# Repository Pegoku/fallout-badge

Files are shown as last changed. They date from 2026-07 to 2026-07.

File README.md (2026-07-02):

# Small Morse Code Handheld Devices

From: @Pegoku

ESP32-C3 based boards that connect to each other and let you send and receive messages using ESPNOW.

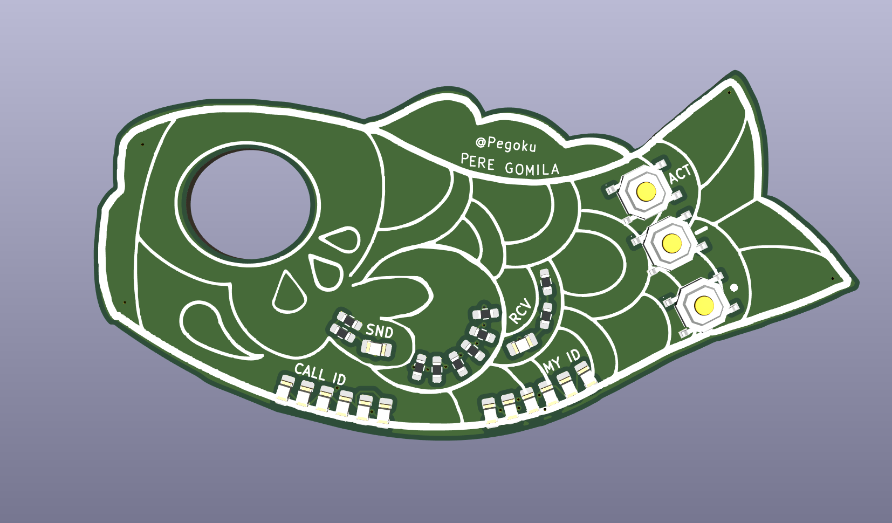
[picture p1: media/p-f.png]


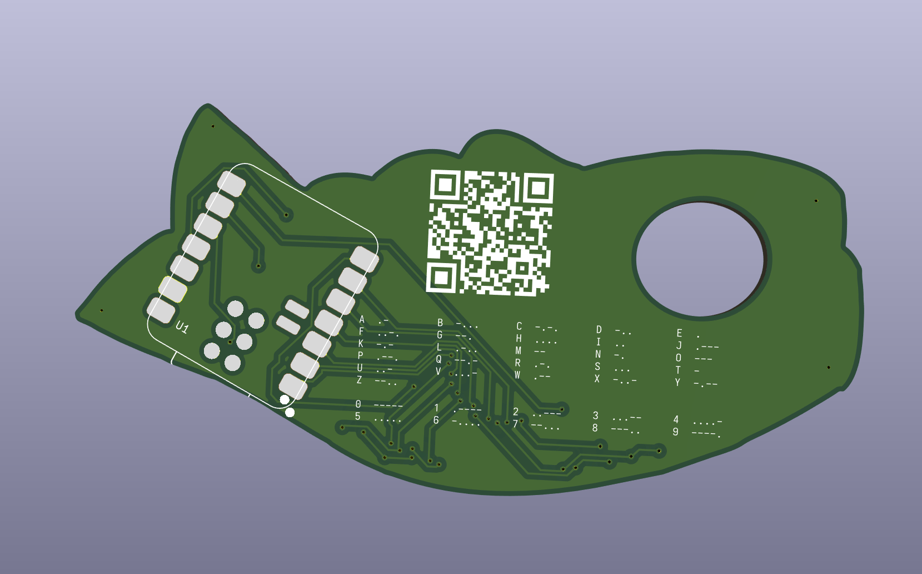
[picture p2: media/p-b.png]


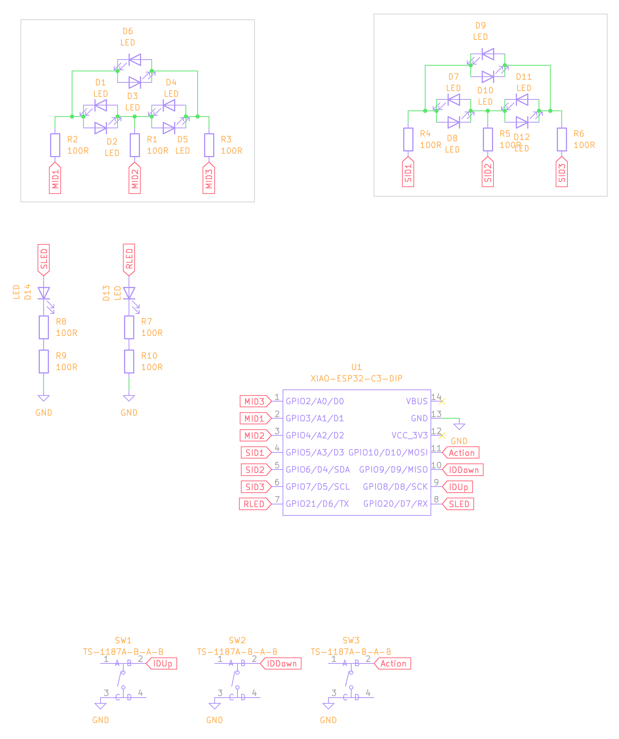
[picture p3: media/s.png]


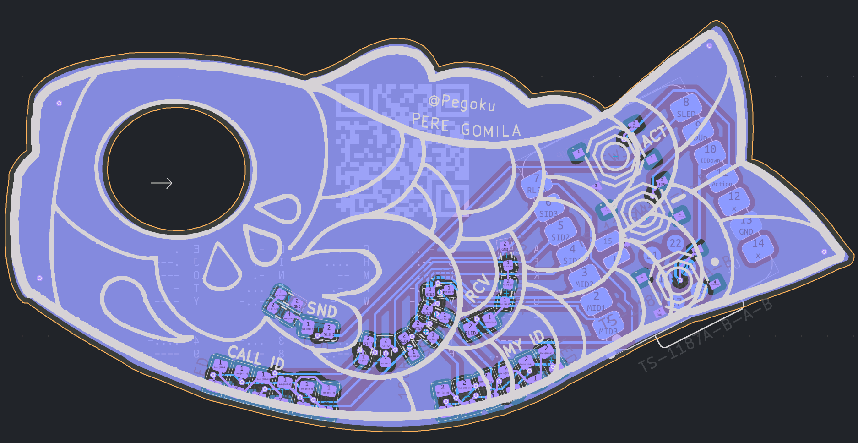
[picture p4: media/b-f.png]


## BOM (Per PCB)

| Item | Quantity | JLCPCB PN. |
| --- | --- | --- |
| XIAO ESP32-C3  | 1 | N/A |
| 100 Ω resistor | 10 | C22775 |
| Push button | 3 | C318884 |
| 0805 Red LED | 14 | C84256 |

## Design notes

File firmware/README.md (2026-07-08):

# Fallout Badge Firmware

Firmware for the ESP32-C3 Fallout badge.

Current firmware status: full ESP-NOW application firmware. It stores a local
badge ID, validates claimed IDs over ESP-NOW, selects a call target, handles
incoming/outgoing calls, and exchanges short/long/raw call inputs.

## Requirements

- ESP-IDF 6.x
- ESP32-C3 devboard connected over USB
- `cmake`, `ninja`, and the ESP-IDF toolchain

On this machine ESP-IDF is installed at:

```sh
/opt/esp-idf
```

Before using `idf.py`, source the ESP-IDF environment:

```sh
. /opt/esp-idf/export.sh
```

## Select Board Pinout

Two ESP32-C3 mini devboard pinouts are supported. They use the same physical
connector positions, but the GPIO numbers printed on the boards differ.

Default:

```text
ESP32-C3 mini:       5V GND 3.3V 10 9 8 7 6 5 4 3 2 1 0
```

For the default XIAO ESP32-C3 schematic, the ID LEDs and buttons use the
working `GPIO10..GPIO2` mapping, while the two discrete indicators are wired
separately as `RLED=GPIO21` and `SLED=GPIO20`.

Alternative:

```text
ESP32-C3 Super Mini: 5V GND 3.3V 4 3 2 1 20 10 9 8 7 6 5
```

The Super Mini option applies this XIAO-to-Super-Mini signal remap:

```text
XIAO GPIO:        2 3 4 5 6 7 21 20 10 9 8
Super Mini GPIO: 5 6 7 8 9 10 20 1  4  3 2
```

To change the selected board:

```sh
. /opt/esp-idf/export.sh
idf.py menuconfig
```

Then choose:

```text
Fallout Badge -> ESP32-C3 devboard pinout
```

The default board is also set in `sdkconfig.defaults`:

```text
CONFIG_BADGE_BOARD_PINOUT_C3_MINI=y
```

## Build

```sh
. /opt/esp-idf/export.sh
idf.py set-target esp32c3
idf.py build
```

The output firmware is:

```text
build/fallout_badge.bin
```

## Flash And Monitor

With one ESP32-C3 connected:

```sh
. /opt/esp-idf/export.sh
idf.py flash monitor
```

If multiple serial devices are connected, pass the port explicitly:

```sh
idf.py -p /dev/ttyACM0 flash monitor
```

Exit the monitor with `Ctrl+]`.

## Usage

After flashing:

- The firmware logs the selected pinout at boot.
- The firmware logs the concrete GPIO map used for LEDs and buttons.
- If no local ID is saved, the badge enters My ID input.
- If a local ID is saved, the badge enters Main mode and shows it on My ID LEDs.

Controls:

- My ID input: `IDUp`/`IDDown` changes the local ID, including `0`.
- My ID input: hold `IDUp` or `IDDown` for 0.8 seconds to auto-repeat with acceleration.
- My ID input: `Action` validates and saves the selected ID. Selecting `0` runs automatic assignment.
- Main: `IDUp` or `IDDown` enters Who To Call mode.
- Main or Who To Call: hold `IDUp + IDDown` for 3 seconds to re-enter My ID input.
- Who To Call: `IDUp`/`IDDown` changes the target ID.
- Who To Call: hold `IDUp` or `IDDown` for 0.8 seconds to auto-repeat with acceleration.
- Who To Call: `Action` sends a call request.
- Who To Call: long-press `Action` cancels back to Main.
- Incoming call: short-press `Action` accepts.
- Incoming call: long-press `Action` rejects.
- Outgoing wait or active call: hold `IDUp + IDDown` for 3 seconds to end/cancel.
- Active call: holding `Action` live-streams the raw input; SLED turns on while pressed and the receiver's RLED mirrors it until release.
- Active call: short-press `IDDown` sends a short visible symbol.
- Active call: short-press `IDUp` sends a long visible symbol.
- Active call: short/long symbols are queued and sent sequentially with a short gap between pulses.
- Directed packets are acknowledged and retried if the ACK is missed, including call requests, call responses, call end, and active-call inputs. Broadcast discovery packets remain best-effort.

Display behavior:

- My ID LEDs show the local badge ID.
- Send ID LEDs show the selected target, incoming caller, or active peer.
- The editable LED group blinks in My ID input and Who To Call modes.
- SLED pulses on local sends and stays on while holding `Action` in an active call.
- SLED/RLED hold for readable short and long symbol durations during active-call inputs.
- RLED mirrors received raw-duration inputs.
- Incoming calls blink SLED and RLED together.

## Hardware Notes

- Buttons are configured as active-low with internal pull-ups.
- Some GPIOs are boot strapping pins depending on the selected board. Test reset behavior while holding each button.
- The default XIAO ESP32-C3 schematic puts RLED/SLED on GPIO21/GPIO20. These are UART-labelled pins, so console logging is configured for USB Serial/JTAG instead of UART.
- Charlieplex LED 0 is the rightmost LED.
- The measured My ID scan appeared as `4 3 2 5 1 0`, so My ID defaults to order `{1, 0, 2, 5, 4, 3}` in `main/badge_display.c`.
- The measured Call ID scan appeared as `4 5 0 1 2 3`, so Call ID defaults to order `{4, 5, 2, 3, 0, 1}` in `main/badge_display.c`.

## Useful Commands

Clean and rebuild:

```sh
idf.py fullclean
idf.py build
```

Open config:

```sh
idf.py menuconfig
```

Show configured badge pinout symbols:

```sh
rg "BADGE_BOARD_PINOUT" sdkconfig
```

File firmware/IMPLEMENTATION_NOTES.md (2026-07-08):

# Firmware Implementation Notes

## Current Status

Started Phase 1 and Phase 2 from `ImprovedPlan.md`.

Implemented:

- Native ESP-IDF project scaffold.
- ESP32-C3 devboard pin map toggle for the two supported mini-board pinouts.
- Initial charlieplex display driver for My ID and Send ID LEDs.
- Configurable logical-to-physical LED order arrays.
- Fixed SLED/RLED control and pulse helpers.
- Initial debounced button polling for IDUp, IDDown, and Action.
- Basic bring-up `app_main` that scans LED patterns and logs button events.

## Build Status

Native ESP-IDF is installed system-wide:

- ESP-IDF package: `esp-idf 6.0.1-1`.
- ESP-IDF path: `/opt/esp-idf`.
- Build tool: `/opt/esp-idf/tools/idf.py`.

`idf.py` is not on `PATH` until the ESP-IDF environment is sourced. Use:

```sh
. /opt/esp-idf/export.sh
```

Verified build command:

```sh
. /opt/esp-idf/export.sh && idf.py set-target esp32c3 && idf.py build
```

Build result:

- `build/fallout_badge.bin` generated successfully.
- App binary size: about `0x23350` bytes.
- Smallest app partition free space: about 86%.

Known environment warnings:

- Git reports dubious ownership for `/opt/esp-idf` because the package files are owned by `nobody`. The build still completes.
- ESP-IDF reports a few upstream Kconfig default-value notifications. They do not block this project build.

## Build And Flash Commands

From this directory, in a new shell:

```sh
. /opt/esp-idf/export.sh
idf.py set-target esp32c3
idf.py build
idf.py flash monitor
```

## Board Pinout Selection

The badge maps logical signals by physical connector position. Both supported
boards use the same positions, but the GPIO labels differ.

Default board:

```text
ESP32-C3 mini:       5V GND 3.3V 10 9 8 7 6 5 4 3 2 1 0
```

For the default XIAO ESP32-C3 schematic, the ID LEDs and buttons use the
working `GPIO10..GPIO2` mapping, while the two discrete indicators are wired
separately as `RLED=GPIO21` and `SLED=GPIO20`.

Alternative board:

```text
ESP32-C3 Super Mini: 5V GND 3.3V 4 3 2 1 20 10 9 8 7 6 5
```

The Super Mini firmware option applies this XIAO-to-Super-Mini signal remap:

```text
XIAO GPIO:        2 3 4 5 6 7 21 20 10 9 8
Super Mini GPIO: 5 6 7 8 9 10 20 1  4  3 2
```

To change the board:

```sh
. /opt/esp-idf/export.sh
idf.py menuconfig
```

Then select:

```text
Fallout Badge -> ESP32-C3 devboard pinout
```

The default can also be changed in `sdkconfig.defaults`.

Logical signal order across the 11 GPIO positions:

```text
Action IDDown IDUp SID3 SID2 SID1 MID2 MID1 MID3 RLED SLED
```

## Hardware Bring-Up Notes

- Buttons are currently configured as active-low with internal pull-ups.
- Some selected GPIOs are boot strapping sensitive depending on the board. Test reset behavior while holding each button.
- The default XIAO ESP32-C3 schematic puts RLED/SLED on GPIO21/GPIO20. These are UART-labelled pins, so serial logging should stay on USB Serial/JTAG rather than UART.
- Charlieplex LED 0 is the rightmost LED.
- The measured My ID scan appeared as `4 3 2 5 1 0`, so My ID defaults to order `{1, 0, 2, 5, 4, 3}` to display visible LED order `0 1 2 3 4 5`.
- The measured Call ID scan appeared as `4 5 0 1 2 3`, so Call ID defaults to order `{4, 5, 2, 3, 0, 1}` to display visible LED order `0 1 2 3 4 5`.

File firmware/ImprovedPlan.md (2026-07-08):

# Fallout Badge Firmware Plan

## Feasibility Review

The feature set is feasible on the XIAO ESP32-C3 with ESP-NOW and FreeRTOS/ESP-IDF. The current hardware appears to fit the required signals exactly:

| Function | Net | XIAO / ESP32-C3 GPIO |
| --- | --- | --- |
| My ID charlieplex A | MID1 | GPIO3 / D1 |
| My ID charlieplex B | MID2 | GPIO4 / D2 |
| My ID charlieplex C | MID3 | GPIO2 / D0 |
| Send ID charlieplex A | SID1 | GPIO5 / D3 |
| Send ID charlieplex B | SID2 | GPIO6 / D4 |
| Send ID charlieplex C | SID3 | GPIO7 / D5 |
| Receive indicator LED | RLED | GPIO21 / D6 / TX |
| Send indicator LED | SLED | GPIO20 / D7 / RX |
| ID up button | IDUp | GPIO8 / D8 |
| ID down button | IDDown | GPIO9 / D9 |
| Action button | Action | GPIO10 / D10 |

Main risks and improvements:

1. GPIO8 and GPIO9 can affect ESP32-C3 boot strapping depending on board wiring and pull state. Validate that the buttons do not hold the chip in a bad boot mode when pressed during reset.
2. GPIO20/GPIO21 are UART RX/TX pins. Using them for LEDs is fine, but serial logging over those pins should be disabled or moved to USB CDC during normal firmware.
3. Automatic ID assignment cannot be guaranteed by simply pinging random IDs because two badges can choose the same ID at the same time. Use a probe/claim handshake with random backoff and store the accepted ID in NVS.
4. ESP-NOW is appropriate for short low-latency packets, but it is not guaranteed delivery. Add sequence numbers, acknowledgements for call control packets, and tolerate dropped realtime button-duration packets.
5. Charlieplexing and button scanning must be coordinated so display refresh does not cause ghosting or accidental button reads. Keep LED refresh in one task/driver and keep buttons on independent GPIO inputs with debounce.

## Firmware Stack

Use native ESP-IDF with FreeRTOS. Keep the code structured as ESP-IDF components:

- `app_main`: initializes NVS, GPIO, display, buttons, ESP-NOW, and app state.
- `drivers/display`: charlieplex refresh and fixed indicator LEDs.
- `drivers/buttons`: debounced button events with press, release, hold, and chord detection.
- `comms/espnow`: peer setup, packet encode/decode, send queue, receive callback.
- `app/state_machine`: all badge modes and transitions.
- `app/id_manager`: manual ID selection, automatic ID probing, NVS persistence.
- `app/call_session`: call setup, accept/reject/end, realtime message exchange, inactivity timeout.

## Core Data Model

IDs are 6-bit values:

- `0`: reserved for "auto assign / unset"; never used as a normal badge ID.
- `1..63`: valid badge IDs.
- Broadcast ESP-NOW peer is used for discovery, ID probing, and initial call requests.

Runtime state:

- `my_id`: current local badge ID.
- `target_id`: selected outgoing call target.
- `mode`: current UI state.
- `active_call_peer_id`: remote ID for the active call, if any.
- `last_activity_ms`: updated by accepted call traffic and local call input.
- `pending_call`: incoming caller ID and timeout data.
- `held_callers`: small list or bitset of callers that tried to call during an active call.

Persistent NVS values:

- Last confirmed `my_id`.
- Optional firmware/protocol version for future migrations.

## ESP-NOW Protocol

Use a compact fixed binary packet. Every packet includes:

- `magic`: identifies this project.
- `version`: protocol version.
- `type`: packet type.
- `src_id`: sender badge ID.
- `dst_id`: destination badge ID, or `0` for broadcast.
- `seq`: monotonically increasing packet sequence.
- `payload`: packet-specific data.

Packet types:

- `ID_PROBE`: asks whether an ID is already in use.
- `ID_PROBE_ACK`: sent by a badge that owns the probed ID.
- `ID_CLAIM`: announces that a badge is claiming an ID after a quiet probe window.
- `ID_CONFLICT`: optional warning sent when a badge sees another badge using its own ID.
- `CALL_REQUEST`: asks a target badge to start a call.
- `CALL_ACCEPT`: accepts a pending call.
- `CALL_REJECT`: rejects a pending call.
- `CALL_HOLD`: tells a caller that the target is busy but noticed the request.
- `CALL_END`: ends an active call.
- `CALL_INPUT_RAW`: sends an action-button duration in milliseconds.
- `CALL_INPUT_SHORT`: sends a short symbol.
- `CALL_INPUT_LONG`: sends a long symbol.
- `PING`: optional presence/keepalive.

Reliability rules:

- Control packets (`CALL_REQUEST`, `CALL_ACCEPT`, `CALL_REJECT`, `CALL_HOLD`, `CALL_END`, `ID_CLAIM`, `ID_CONFLICT`) are resent a small fixed number of times until acknowledged or timed out.
- Realtime input packets may be sent once to preserve responsiveness.
- Duplicate packets are ignored using `(src_id, seq)`.

## Build System Decision

Use native ESP-IDF as the primary developer workflow. This aligns the project with Espressif's official tooling and keeps Wi-Fi/ESP-NOW configuration, flashing, monitoring, and debugging closest to the upstream documentation.

PlatformIO pros:

- Easier dependency, serial monitor, upload, and board configuration workflow.
- Good fit for quick iteration from VS Code or the command line.
- Can still target ESP-IDF instead of Arduino.

PlatformIO cons:

- Adds one extra layer between the project and upstream ESP-IDF.
- Some ESP-IDF examples/docs assume native `idf.py`, so commands may need translation.
- Advanced ESP-IDF configuration can be slightly less transparent.

Native ESP-IDF pros:

- Official Espressif workflow with best documentation alignment.
- Simplest path for advanced Wi-Fi/ESP-NOW debugging and SDK configuration.
- Less abstraction when chasing low-level build or runtime issues.

Native ESP-IDF cons:

- More setup friction for contributors.
- Board/upload/monitor workflow is less compact than PlatformIO for small projects.
- Requires everyone to keep the ESP-IDF environment installed and sourced correctly.

Decision:

- Primary workflow: native ESP-IDF with `idf.py`.
- Optional future workflow: PlatformIO can be added later as a convenience wrapper if useful.
- The source tree should avoid PlatformIO-only assumptions.

## UI State Machine

### Boot

1. Initialize drivers and ESP-NOW.
2. Load `my_id` from NVS.
3. If no saved ID exists, enter `MY_ID_INPUT` with value `0`.
4. If a saved ID exists, display it on My ID LEDs and enter `MAIN`.

### My ID Input

Purpose: choose this badge's own ID.

Display:

- My ID LEDs blink while value is `0`.
- My ID LEDs show the selected 6-bit value for `1..63`.
- Send ID LEDs stay off.

Controls:

- `IDUp`: increment selected ID, wrapping `63 -> 0`.
- `IDDown`: decrement selected ID, wrapping `0 -> 63`.
- `Action` short press:
  - If selected ID is `1..63`, validate that the ID is not already in use before saving it and entering `MAIN`.
  - If selected ID is `0`, run automatic ID assignment.

Manual ID validation:

1. Broadcast `ID_PROBE(selected_id)`.
2. Wait a randomized probe window.
3. If any `ID_PROBE_ACK` is received, show an error blink/dance and stay in `MY_ID_INPUT`.
4. If no owner replies, broadcast `ID_CLAIM(selected_id)`, save it, and enter `MAIN`.

Automatic ID assignment:

1. Pick a random candidate from `1..63`.
2. Broadcast `ID_PROBE(candidate)`.
3. Wait a randomized probe window.
4. If no `ID_PROBE_ACK` is received, broadcast `ID_CLAIM(candidate)`.
5. Wait a second short randomized window.
6. If no conflict appears, save the ID and enter `MAIN`.
7. If a conflict appears, try a different candidate.

### Main

Purpose: idle, show this badge's ID, and listen for calls.

Display:

- My ID LEDs show `my_id`.
- Send ID LEDs off.
- SLED/RLED off except for brief receive/send activity pulses.

Controls:

- `IDUp` or `IDDown` short press: enter `WHO_TO_CALL`.
- Hold `IDUp + IDDown` for 3 seconds: enter `MY_ID_INPUT`.

Comms:

- Listen for `CALL_REQUEST` with `dst_id == my_id`.
- On valid incoming call, store caller ID and enter `CALL_RECEIVED`.
- If an `ID_PROBE` arrives for `my_id`, reply with `ID_PROBE_ACK`.
- If an `ID_CLAIM` or normal packet is seen from another badge using `my_id`, send `ID_CONFLICT` and show a conflict alert.

### Call Received

Purpose: accept or reject an incoming call.

Display:

- Blink SLED and RLED together.
- My ID LEDs continue showing `my_id`.
- Send ID LEDs show caller ID.

Controls:

- `Action` short press: send `CALL_ACCEPT`, enter `CALLING`.
- `Action` long press: send `CALL_REJECT`, enter `MAIN`.

Timeout:

- If the user does not respond within a configurable timeout, send `CALL_REJECT` and enter `MAIN`.

### Who To Call

Purpose: choose the remote badge ID.

Display:

- My ID LEDs show `my_id`.
- Send ID LEDs show selected `target_id`.

Controls:

- `IDUp`: increment target ID, wrapping `63 -> 1`.
- `IDDown`: decrement target ID, wrapping `1 -> 63`.
- `Action` short press: send `CALL_REQUEST`, enter `CALLING`.
- `Action` long press: clear target ID and return to `MAIN`.

Validation:

- Do not allow `target_id == 0`.
- If `target_id == my_id`, blink both ID groups as an error and stay in `WHO_TO_CALL`.

### Calling

Purpose: establish or run a bidirectional call.

Substates:

- `OUTGOING_WAIT_ACCEPT`: call request sent, waiting for accept/reject.
- `ACTIVE`: remote accepted; both badges can exchange messages.

Display:

- My ID LEDs show `my_id`.
- Send ID LEDs show remote ID.
- Pulse SLED on local send for short/long symbols and control traffic.
- Pulse RLED on remote receive for short/long symbols and control traffic.
- For raw action-button duration messages, the sender's SLED stays on for the full local press duration, and the receiver's RLED mirrors that duration. In the other direction, their SLED and my RLED should mirror the same way.

Controls in `OUTGOING_WAIT_ACCEPT`:

- Hold `IDUp + IDDown`: send `CALL_END`, enter `MAIN`.

Controls in `ACTIVE`:

- `Action` press/release: send `CALL_INPUT_RAW` with press duration in milliseconds.
- `IDDown` short press: send `CALL_INPUT_SHORT`.
- `IDUp` short press: send `CALL_INPUT_LONG`.
- Hold `IDUp + IDDown`: send `CALL_END`, enter `MAIN`.

Incoming calls during `ACTIVE`:

- Calls are strictly one-to-one.
- If a third badge sends `CALL_REQUEST`, reply with `CALL_HOLD` instead of accepting or rejecting.
- Add the caller to `held_callers` if there is room.
- Play a short "busy dance" on the Send ID LEDs, for example sweeping the six Send ID LEDs twice while preserving the active call state.
- When the active call ends, return to `MAIN`; held callers must call again rather than being auto-connected.

Timeouts:

- If the outgoing call is rejected or times out, enter `MAIN`.
- If there is 30 seconds of inactivity in `ACTIVE`, send `CALL_END` and enter `MAIN`.
- The inactivity timeout should be configurable with a compile-time constant.

## Display Driver Plan

Charlieplexing:

- Each 3-pin LED group controls 6 LEDs.
- Only one charlieplexed LED should be driven at a time per group.
- To light LED `n`, set one pin high, one pin low, and all other group pins high impedance.
- Refresh both 6-LED groups at a stable interval from a single display task or timer.

Display API:

- `display_set_my_id(uint8_t id, bool blink)`
- `display_set_target_id(uint8_t id, bool blink)`
- `display_pulse_send()`
- `display_pulse_receive()`
- `display_set_send_led(bool enabled)`
- `display_set_receive_led(bool enabled)`
- `display_set_call_alert(bool enabled)`
- `display_play_busy_dance()`
- `display_play_error_dance()`
- `display_tick()` if implemented without a dedicated task.

Implementation note:

- Start with a simple blocking scan during bring-up, then move refresh to a FreeRTOS task once button and comms code exists.
- LED bit order must be configurable with arrays, for example `my_id_led_order[6] = {0, 1, 2, 5, 4, 3}` and `send_id_led_order[6] = {0, 1, 2, 3, 4, 5}`. The state machine should think in logical bit positions; only the display driver maps those positions to physical LED indices.

## Button Driver Plan

Inputs:

- `IDUp`
- `IDDown`
- `Action`

Events:

- `BUTTON_PRESS`
- `BUTTON_RELEASE`
- `BUTTON_SHORT`
- `BUTTON_LONG`
- `BUTTON_HOLD_3S`
- `BUTTON_CHORD_UP_DOWN_3S`

Timing constants:

- Debounce: 20-40 ms.
- Long press: 600-1000 ms.
- Mode-change chord: 3000 ms.

The button driver should publish events to a FreeRTOS queue. The state machine consumes events and owns all interpretation.

## Implementation Milestones

### Phase 1: Project Scaffold

- Add ESP-IDF project files.
- Configure target for ESP32-C3/XIAO.
- Enable USB CDC logging if available.
- Add `sdkconfig.defaults` with Wi-Fi/ESP-NOW-friendly defaults.
- Confirm the firmware builds and boots.

Done when:

- A minimal firmware builds.
- Boot logs are visible.
- The app prints firmware version and reset reason.

### Phase 2: Hardware Bring-Up

- Define the GPIO pin map from the PCB.
- Implement fixed SLED/RLED control.
- Implement charlieplex LED test patterns.
- Implement configurable logical-to-physical LED order arrays for both charlieplex groups.
- Implement button input with debounce and event logging.

Done when:

- Every LED can be lit individually.
- Binary values can be displayed correctly after adjusting the LED order arrays.
- Every button reports short and long presses.
- Pressing buttons during reset does not break boot, or the risk is documented with a hardware workaround.

### Phase 3: Local UI State Machine

- Implement `MY_ID_INPUT`, `MAIN`, `WHO_TO_CALL`, and local transitions.
- Implement NVS save/load for `my_id`.
- Add display rendering for IDs and blinking/error states.

Done when:

- A single badge can select and persist its own ID.
- A target ID can be selected and cancelled.
- All local controls match the state machine.

### Phase 4: ESP-NOW Transport

- Initialize Wi-Fi station mode and ESP-NOW.
- Add broadcast peer.
- Implement packet struct, sequence numbers, duplicate filtering, and receive queue.
- Add debug command/log mode for sending test packets.

Done when:

- Two badges can exchange basic `PING` packets.
- SLED/RLED pulse on transmit/receive.
- Duplicate filtering is verified.

### Phase 5: ID Assignment

- Implement `ID_PROBE`, `ID_PROBE_ACK`, and `ID_CLAIM`.
- Use the same probe/claim flow for manual ID selection and automatic ID selection.
- Implement optional `ID_CONFLICT` handling for detected duplicate IDs.
- Add randomized backoff and conflict handling.
- Persist the assigned ID.

Done when:

- Multiple badges powered on together usually pick unique IDs.
- Manual ID conflicts are detected before saving when the conflicting badge is reachable.
- Duplicate-ID warnings are visible to the user when a conflict is detected later.

### Phase 6: Call Setup

- Implement `CALL_REQUEST`, `CALL_ACCEPT`, `CALL_REJECT`, `CALL_HOLD`, and `CALL_END`.
- Add outgoing wait, incoming call alert, accept/reject controls, and call cancellation.
- Add one-to-one busy handling and the busy dance for calls received during an active call.
- Add retries for control packets.

Done when:

- Badge A can call badge B.
- Badge B can accept or reject.
- Badge B replies with hold/busy behavior if Badge C calls while Badge B is already in a call.
- Both badges return to `MAIN` on reject, timeout, or call end.

### Phase 7: Realtime Call Input

- Implement raw action-button duration messages.
- Implement short and long symbol messages from `IDDown` and `IDUp`.
- Keep local SLED on for the full raw action-button press duration.
- Keep remote RLED on for the received raw action-button duration.
- Keep call traffic non-blocking with send/receive queues.
- Add 30-second inactivity timeout.

Done when:

- Inputs can be exchanged in both directions during an active call.
- The sender's SLED and receiver's RLED stay synchronized for raw duration messages in both directions.
- Sending does not block receiving.
- Inactivity and manual end both close the call cleanly.

### Phase 8: Polish and Hardening

- Tune button timings and LED refresh rate.
- Reduce logging for release builds.
- Add packet version checks.
- Add basic fault handling for ESP-NOW send failures.
- Add a simple diagnostics mode if flash space allows.

Done when:

- Two or more badges can run through the full flow repeatedly.
- Cold boot, reset, and reconnect behavior are predictable.
- Known limitations are documented in `README.md`.

## Test Plan

Single badge tests:

- Boot with no saved ID.
- Manual ID selection for `1`, `63`, and wraparound.
- Auto ID path with no other badges present.
- Button short, long, and chord detection.
- All LEDs and binary display values.
- NVS persistence across reset.

Two badge tests:

- Manual unique IDs and ping.
- Manual duplicate ID attempt while the other badge is reachable.
- Incoming call accept.
- Incoming call reject.
- Outgoing call timeout.
- Manual call end from either side.
- Raw duration send accuracy within acceptable tolerance.
- Sender SLED and receiver RLED synchronization during raw action-button messages.
- Short/long symbol exchange in both directions.

Multi badge tests:

- Auto ID assignment with three or more badges.
- Two badges attempting the same ID.
- One badge receiving a call while another call request is nearby.
- Busy/hold response and busy dance while already in an active call.
- Packet loss simulation by increasing distance or shielding one badge.

## Finalized Decisions

- Active calls are one-to-one. Extra callers receive `CALL_HOLD`, and the called badge plays a short Send ID LED busy dance.
- Manual ID selection uses the same probe/claim conflict avoidance as automatic ID assignment.
- The primary workflow is native ESP-IDF with `idf.py`.
- LED bit order is configurable with arrays in the display driver.
- Raw action-button messages are visualized as synchronized duration indicators: sender SLED on while pressed, receiver RLED on for the same duration.

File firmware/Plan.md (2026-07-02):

## Hardware capabilities:
XIAO ESP32-C3
6 My ID LEDs charlieplexed
6 Your ID LEDs charlieplexed
1 Send LED (to check what you're sending)
1 Recieve LED (to check what you're recieving)

For more information on how the components are connected, check ../pegoku-fallout-badge's schematic.

## Functionality

The device has many modes/states it can be in.

### My ID input mode

After powering on, it will be in this mode. It will ask for an ID, and the "My Id" LEDs will blink until the user press up or down, and then it will, in binary, display the ID. It goes from 000001 to 111111 (1 to 63)
then, you'll need to press the action button.

If the id is 000000, it will check for which id is available, by "pinging" each other device by using random IDs until the id is "unique".

Now, the My ID LEDs will be set to your id.

### Main Mode

This mode is the default idle mode.

To enter My Id input mode you have to press and hold for 3 seconds both up and down buttons.

If you just press up or down, like one tap, it will enter Who to call mode.

While in this mode it will frequently check for calls to this device, if it recieves one, will go to Call Recieved mode.

### Call recieved mode

In this mode, both RLED and SLED will blink and the user can accept (by pressing the action button) or reject the call by holding the button down for longer. 

If it rejects it, it will go back to main mode.
If it accepts it it will enter Calling Mode.

### Who to call mode

In this mode, the user has to set an ID of which they want to call to, that's the Send LEDs. It will be inputed in the same way as the My ID input mode.
When the ID is set and the user presses the Action button, it will start start the call, and enter the calling mode

If the user Holds down the action button, it will clear the id it was selected and go back to the main mode.

### Calling mode 

In this mode, it will send a message to the device with the ID specified, and wait for the other device to accept or reject it.

If it is rejected, it will go back to main mode.

When the user accepts the call, the call will begin, and bidirectionally the message interaction will be possible.

When the action button is pressed, it will send the "raw" duration of the press, so if the user presses for 312ms, 312ms will be sent.

But if the user presses the IDUp button, it will send a long message, and if they press the IDDown it will send a short message (morse code style).

The communication should be real time, not wait for the message to continue.

After 15 seconds of inactivity (configurable via #DECLARE) it will stop the call.

If the user wants to end the call early, they can press and hold both up and down buttons and it will end the call.

## Software

The project should use a RTOS (e.g. ESP-IDF)

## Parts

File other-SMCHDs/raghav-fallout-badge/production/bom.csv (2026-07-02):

Designator | Footprint | Quantity | Value | LCSC Part #
D1, D10, D11, D12, D13, D14, D2, D3, D4, D5, D6, D7, D8, D9 | 0805 | 14 | LED | C84256
R1, R10, R2, R3, R4, R5, R6, R7, R8, R9 | 0603 | 10 | 100R | C22775
SW1, SW2, SW3 | SW-SMD_4P-L5.1-W5.1-P3.70-LS6.5-TL_H1.5 | 3 | TS-1187A-B-A-B | C318884
U1 | XIAO-ESP32C3-SMD | 1 | XIAO-ESP32-C3-DIP

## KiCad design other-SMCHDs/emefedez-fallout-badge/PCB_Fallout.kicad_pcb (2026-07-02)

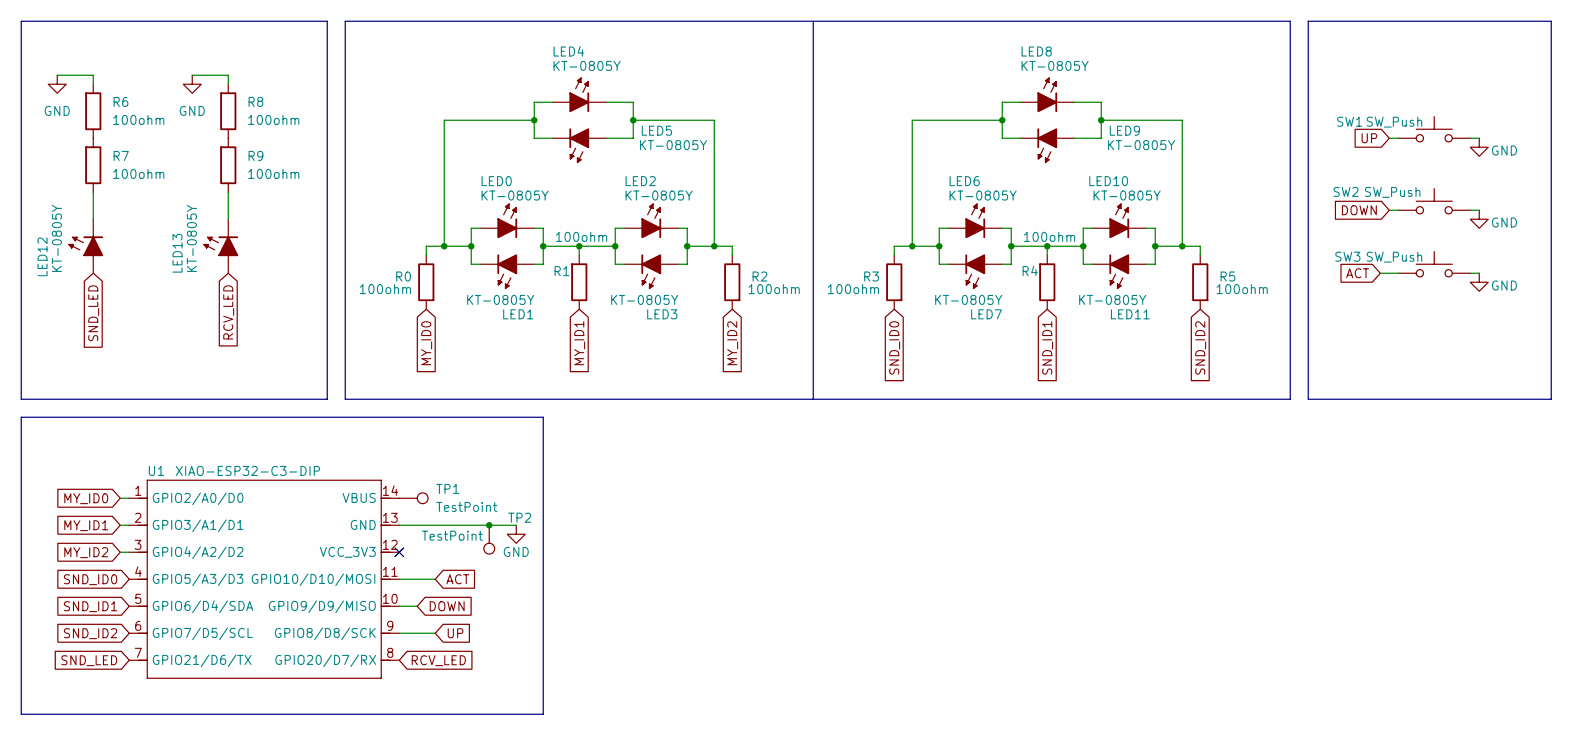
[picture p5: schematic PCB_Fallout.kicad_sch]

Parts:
LED0, LED1, LED2, LED3, LED4, LED5, LED6, LED7, LED8, LED9, LED10, LED11, LED12, LED13: KT-0805Y; LED_PLCC-2_3x2mm_KA
R0, R1, R2, R3, R4, R5, R6, R7, R8, R9: 100ohm; C_0805_2012Metric_Pad1.18x1.45mm_HandSolder
SW1, SW2, SW3: SW_Push; SW_SPST_TL3342
TP1, TP2: TestPoint; TestPoint_Pad_D1.0mm
U1: XIAO-ESP32-C3-DIP

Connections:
ACT: SW3.1, U1.11 (GPIO10/D10/MOSI)
DOWN: SW2.1, U1.10 (GPIO9/D9/MISO)
GND: R6.1, R8.1, SW1.2, SW2.2, SW3.2, TP2.1 (1_1), U1.13 (GND)
MY_ID0: R0.1, U1.1 (GPIO2/A0/D0)
MY_ID1: R1.2, U1.2 (GPIO3/A1/D1)
MY_ID2: R2.1, U1.3 (GPIO4/A2/D2)
unnamed: LED0.2 (A), LED1.1 (K), LED4.2 (A), LED5.1 (K), R0.2
unnamed: LED0.1 (K), LED1.2 (A), LED2.2 (A), LED3.1 (K), R1.1
unnamed: LED2.1 (K), LED3.2 (A), LED4.1 (K), LED5.2 (A), R2.2
unnamed: LED6.2 (A), LED7.1 (K), LED8.2 (A), LED9.1 (K), R3.2
unnamed: LED6.1 (K), LED7.2 (A), LED10.2 (A), LED11.1 (K), R4.1
unnamed: LED8.1 (K), LED9.2 (A), LED10.1 (K), LED11.2 (A), R5.2
unnamed: LED12.1 (K), R7.2
unnamed: LED13.1 (K), R9.2
unnamed: R6.2, R7.1
unnamed: R8.2, R9.1
unnamed: TP1.1 (1_1), U1.14 (VBUS)
RCV_LED: LED13.2 (A), U1.8 (GPIO20/D7/RX)
SND_ID0: R3.1, U1.4 (GPIO5/A3/D3)
SND_ID1: R4.2, U1.5 (GPIO6/D4/SDA)
SND_ID2: R5.1, U1.6 (GPIO7/D5/SCL)
SND_LED: LED12.2 (A), U1.7 (GPIO21/D6/TX)
UP: SW1.1, U1.9 (GPIO8/D8/SCK)

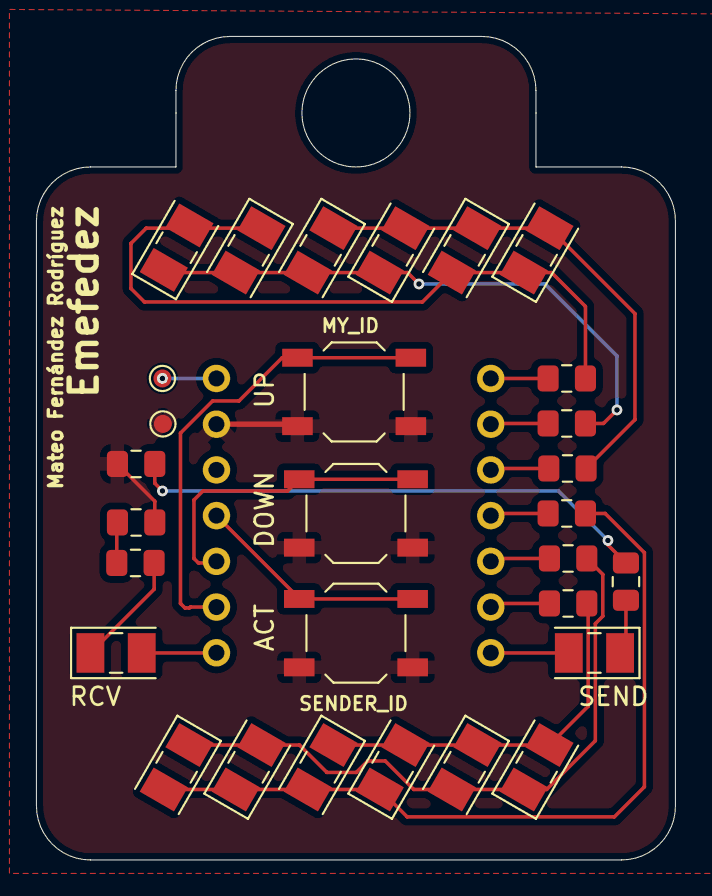
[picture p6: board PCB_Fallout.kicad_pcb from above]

Board: 2 copper layers, 35.5 x 45.8 mm, 30 parts (1 on the bottom side), 23 nets.

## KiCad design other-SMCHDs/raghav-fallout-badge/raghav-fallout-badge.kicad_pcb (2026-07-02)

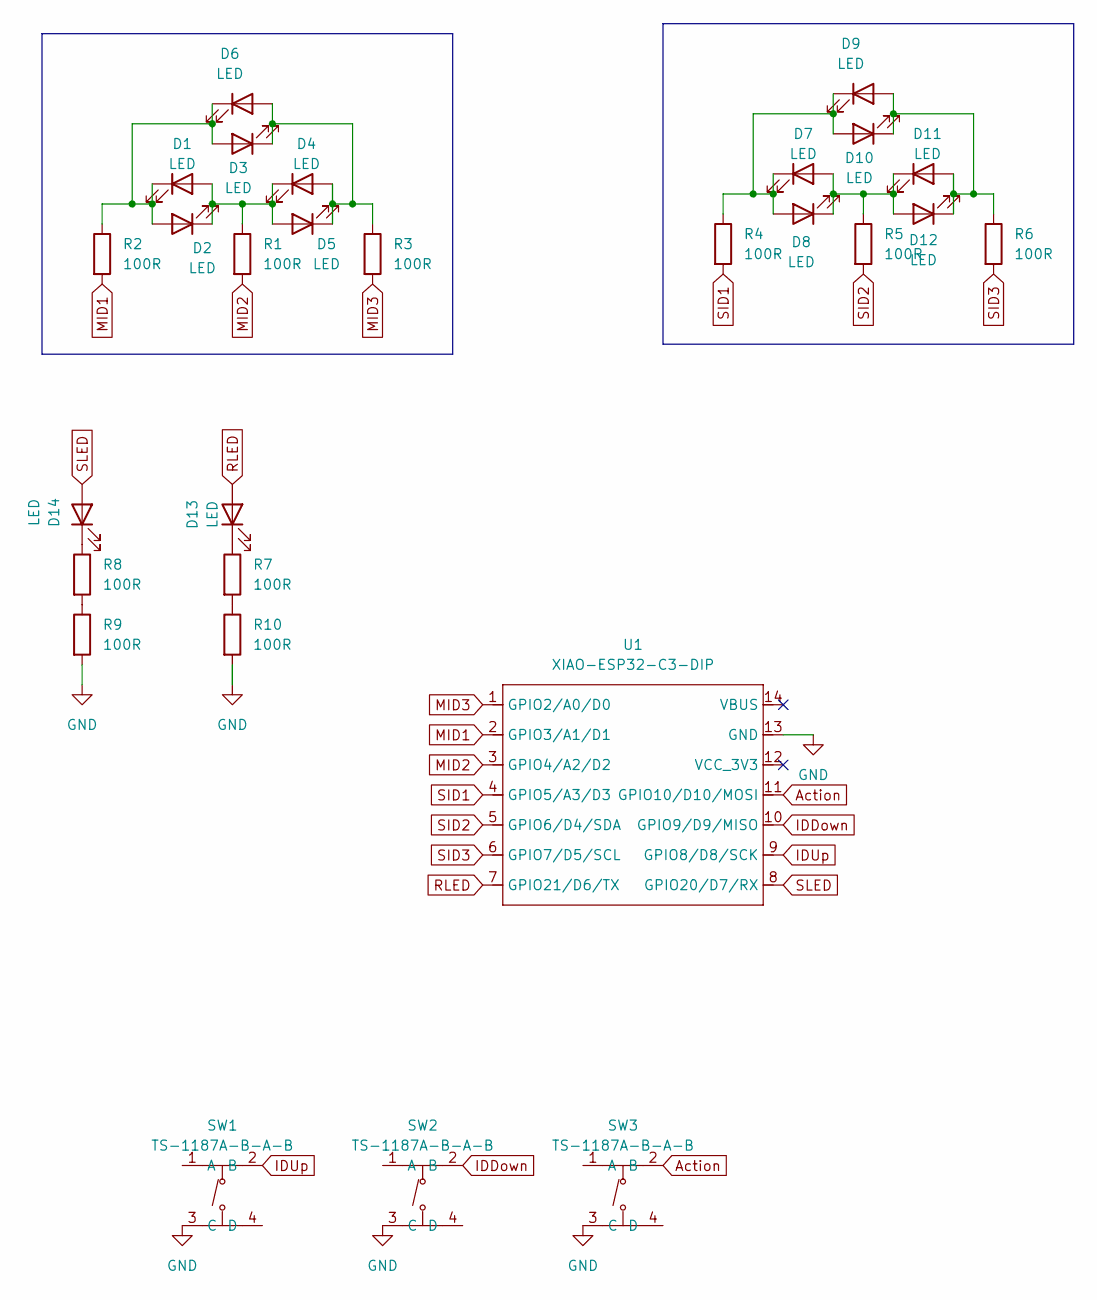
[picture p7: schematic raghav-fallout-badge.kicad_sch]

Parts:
D1, D2, D3, D4, D5, D6, D7, D8, D9, D10, D11, D12, D13, D14: LED; LED_0805_2012Metric_Pad1.15x1.40mm_HandSolder; LCSC Part C84256
R1, R2, R3, R4, R5, R6, R7, R8, R9, R10: 100R; R_0603_1608Metric_Pad0.98x0.95mm_HandSolder; LCSC Part C22775
SW1, SW2, SW3: TS-1187A-B-A-B; SW-SMD_4P-L5.1-W5.1-P3.70-LS6.5-TL_H1.5; MPN TS-1187A-B-A-B; LCSC Part C318884
U1: XIAO-ESP32-C3-DIP; XIAO-ESP32C3-SMD

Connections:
Action: SW3.2 (B), U1.11 (GPIO10/D10/MOSI)
GND: R9.2, R10.2, SW1.3 (C), SW2.3 (C), SW3.3 (C), U1.13 (GND)
IDDown: SW2.2 (B), U1.10 (GPIO9/D9/MISO)
IDUp: SW1.2 (B), U1.9 (GPIO8/D8/SCK)
MID1: R2.2, U1.2 (GPIO3/A1/D1)
MID2: R1.2, U1.3 (GPIO4/A2/D2)
MID3: R3.2, U1.1 (GPIO2/A0/D0)
unnamed: D1.2 (A), D2.1 (K), D4.1 (K), D5.2 (A), R1.1
unnamed: D1.1 (K), D2.2 (A), D3.2 (A), D6.1 (K), R2.1
unnamed: D3.1 (K), D4.2 (A), D5.1 (K), D6.2 (A), R3.1
unnamed: D7.1 (K), D8.2 (A), D9.1 (K), D10.2 (A), R4.1
unnamed: D9.2 (A), D10.1 (K), D11.2 (A), D12.1 (K), R6.1
unnamed: D7.2 (A), D8.1 (K), D11.1 (K), D12.2 (A), R5.1
unnamed: D13.1 (K), R7.1
unnamed: D14.1 (K), R8.1
unnamed: R8.2, R9.1
unnamed: R7.2, R10.1
RLED: D13.2 (A), U1.7 (GPIO21/D6/TX)
SID1: R4.2, U1.4 (GPIO5/A3/D3)
SID2: R5.2, U1.5 (GPIO6/D4/SDA)
SID3: R6.2, U1.6 (GPIO7/D5/SCL)
SLED: D14.2 (A), U1.8 (GPIO20/D7/RX)

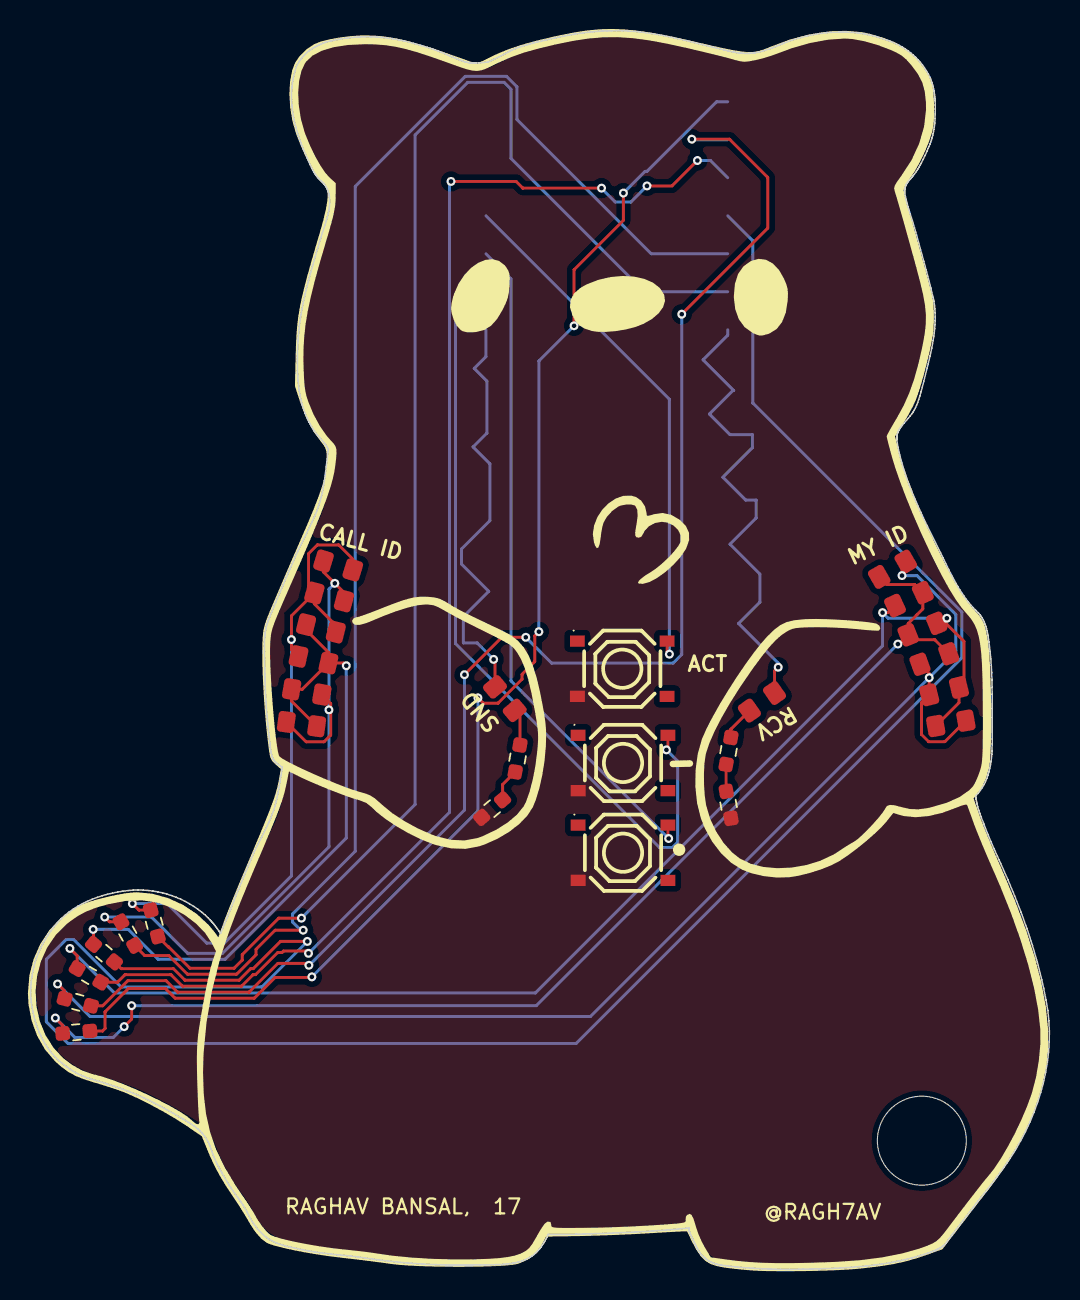
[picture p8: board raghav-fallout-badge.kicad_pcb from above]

Board: 2 copper layers, 68.1 x 82.8 mm, 28 parts (1 on the bottom side), 22 nets.

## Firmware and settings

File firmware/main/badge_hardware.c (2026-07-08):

#include "badge_hardware.h"

#include "sdkconfig.h"

/*
 * Logical badge nets are defined from the default XIAO ESP32-C3 schematic.
 * The Super Mini option remaps those same XIAO GPIO signal assignments to the
 * matching GPIOs on the alternate board.
 *
 * The default XIAO ESP32-C3 footprint uses GPIO20/GPIO21 for the two
 * discrete indicators. Those pins are labelled RX/TX, but the firmware keeps
 * console logging on USB Serial/JTAG so they can be used as normal GPIOs.
 */

#if CONFIG_BADGE_BOARD_PINOUT_C3_SUPER_MINI
#define BADGE_GPIO_MID1 GPIO_NUM_6
#define BADGE_GPIO_MID2 GPIO_NUM_7
#define BADGE_GPIO_MID3 GPIO_NUM_5
#define BADGE_GPIO_SID1 GPIO_NUM_8
#define BADGE_GPIO_SID2 GPIO_NUM_9
#define BADGE_GPIO_SID3 GPIO_NUM_10
#define BADGE_GPIO_RLED GPIO_NUM_20
#define BADGE_GPIO_SLED GPIO_NUM_1
#define BADGE_GPIO_IDUP GPIO_NUM_2
#define BADGE_GPIO_IDDOWN GPIO_NUM_3
#define BADGE_GPIO_ACTION GPIO_NUM_4
#define BADGE_PINOUT_NAME "ESP32-C3 Super Mini"
#else
#define BADGE_GPIO_MID1 GPIO_NUM_3
#define BADGE_GPIO_MID2 GPIO_NUM_4
#define BADGE_GPIO_MID3 GPIO_NUM_2
#define BADGE_GPIO_SID1 GPIO_NUM_5
#define BADGE_GPIO_SID2 GPIO_NUM_6
#define BADGE_GPIO_SID3 GPIO_NUM_7
#define BADGE_GPIO_RLED GPIO_NUM_21
#define BADGE_GPIO_SLED GPIO_NUM_20
#define BADGE_GPIO_IDUP GPIO_NUM_8
#define BADGE_GPIO_IDDOWN GPIO_NUM_9
#define BADGE_GPIO_ACTION GPIO_NUM_10
#define BADGE_PINOUT_NAME "ESP32-C3 mini"
#endif

const badge_pin_map_t BADGE_PINS = {
    .my_id = {
        BADGE_GPIO_MID1,
        BADGE_GPIO_MID2,
        BADGE_GPIO_MID3,
    },
    .send_id = {
        BADGE_GPIO_SID1,
        BADGE_GPIO_SID2,
        BADGE_GPIO_SID3,
    },
    .receive_led = BADGE_GPIO_RLED,
    .send_led = BADGE_GPIO_SLED,
    .button_up = BADGE_GPIO_IDUP,
    .button_down = BADGE_GPIO_IDDOWN,
    .button_action = BADGE_GPIO_ACTION,
};

const char *badge_hardware_pinout_name(void)
{
    return BADGE_PINOUT_NAME;
}

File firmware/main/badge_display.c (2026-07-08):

#include "badge_display.h"

#include <string.h>

#include "badge_hardware.h"
#include "driver/gpio.h"
#include "esp_check.h"
#include "esp_log.h"
#include "esp_timer.h"
#include "freertos/FreeRTOS.h"
#include "freertos/task.h"

static const char *TAG = "badge_display";

typedef struct {
    uint8_t logical_value;
    bool blink;
    bool blink_on;
    uint8_t order[BADGE_ID_LED_COUNT];
} charlie_group_state_t;

static charlie_group_state_t s_my_id = {
    .order = {1, 0, 2, 5, 4, 3},
};

static charlie_group_state_t s_send_id = {
    .order = {4, 5, 2, 3, 0, 1},
};

static uint32_t s_tick_count;
static uint32_t s_send_pulse_ticks;
static uint32_t s_receive_pulse_ticks;
static esp_timer_handle_t s_refresh_timer;
static bool s_send_led_forced;
static bool s_receive_led_forced;
static bool s_send_led_raw_enabled;
static bool s_send_led_raw_level;
static bool s_receive_led_raw_enabled;
static bool s_receive_led_raw_level;
static bool s_send_led_high_z;
static bool s_receive_led_high_z;

static const uint8_t CHARLIE_DRIVE[BADGE_ID_LED_COUNT][2] = {
    {0, 1},
    {1, 0},
    {0, 2},
    {2, 0},
    {1, 2},
    {2, 1},
};

static TickType_t delay_ticks_at_least_one(uint32_t ms)
{
    const TickType_t ticks = pdMS_TO_TICKS(ms);
    return ticks > 0 ? ticks : 1;
}

static void configure_output(gpio_num_t pin, int level)
{
    gpio_reset_pin(pin);
    gpio_set_direction(pin, GPIO_MODE_OUTPUT);
    gpio_set_level(pin, level);
}

static void configure_high_z(gpio_num_t pin)
{
    gpio_reset_pin(pin);
    gpio_set_direction(pin, GPIO_MODE_INPUT);
    gpio_set_pull_mode(pin, GPIO_FLOATING);
}

static void drive_indicator_pin(gpio_num_t pin, int level)
{
    gpio_set_direction(pin, GPIO_MODE_OUTPUT);
    gpio_set_level(pin, level);
}

static void float_indicator_pin(gpio_num_t pin)
{
    gpio_set_direction(pin, GPIO_MODE_INPUT);
    gpio_set_pull_mode(pin, GPIO_FLOATING);
}

static void all_charlie_high_z(const gpio_num_t pins[3])
{
    for (size_t i = 0; i < 3; i++) {
        configure_high_z(pins[i]);
    }
}

static void drive_charlie_led(const gpio_num_t pins[3], uint8_t physical_led)
{
    all_charlie_high_z(pins);

    const uint8_t high_pin = CHARLIE_DRIVE[physical_led][0];
    const uint8_t low_pin = CHARLIE_DRIVE[physical_led][1];

    configure_output(pins[high_pin], 1);
    configure_output(pins[low_pin], 0);
}

static void refresh_timer_callback(void *arg)
{
    (void)arg;
    badge_display_tick();
}

static void render_group(const gpio_num_t pins[3], const charlie_group_state_t *state,
                         uint8_t scan_slot)
{
    if (state->blink && !state->blink_on) {
        all_charlie_high_z(pins);
        return;
    }

    for (uint8_t logical_bit = 0; logical_bit < BADGE_ID_LED_COUNT; logical_bit++) {
        if (((state->logical_value >> logical_bit) & 0x1U) == 0) {
            continue;
        }

        if (scan_slot == logical_bit) {
            const uint8_t physical_led = state->order[logical_bit];
            if (physical_led < BADGE_ID_LED_COUNT) {
                drive_charlie_led(pins, physical_led);
                return;
            }
        }
    }

    all_charlie_high_z(pins);
}

esp_err_t badge_display_init(void)
{
    all_charlie_high_z(BADGE_PINS.my_id);
    all_charlie_high_z(BADGE_PINS.send_id);

    gpio_config_t led_config = {
        .pin_bit_mask = (1ULL << BADGE_PINS.send_led) |
                        (1ULL << BADGE_PINS.receive_led),
        .mode = GPIO_MODE_OUTPUT,
        .pull_up_en = GPIO_PULLUP_DISABLE,
        .pull_down_en = GPIO_PULLDOWN_DISABLE,
        .intr_type = GPIO_INTR_DISABLE,
    };
    ESP_RETURN_ON_ERROR(gpio_config(&led_config), TAG, "indicator GPIO config failed");

    badge_display_set_send_led(false);
    badge_display_set_receive_led(false);

    const esp_timer_create_args_t timer_args = {
        .callback = refresh_timer_callback,
        .name = "display_refresh",
    };
    ESP_RETURN_ON_ERROR(esp_timer_create(&timer_args, &s_refresh_timer), TAG,
                        "display refresh timer create failed");
    ESP_RETURN_ON_ERROR(esp_timer_start_periodic(s_refresh_timer, 1000), TAG,
                        "display refresh timer start failed");

    return ESP_OK;
}

void badge_display_set_my_id(uint8_t id, bool blink)
{
    s_my_id.logical_value = id & 0x3fU;
    s_my_id.blink = blink;
}

void badge_display_set_target_id(uint8_t id, bool blink)
{
    s_send_id.logical_value = id & 0x3fU;
    s_send_id.blink = blink;
}

void badge_display_set_send_led(bool enabled)
{
    s_send_led_raw_enabled = false;
    s_send_led_high_z = false;
    s_send_led_forced = enabled;
}

void badge_display_set_receive_led(bool enabled)
{
    s_receive_led_raw_enabled = false;
    s_receive_led_high_z = false;
    s_receive_led_forced = enabled;
}

void badge_display_set_send_led_raw(bool enabled, bool level)
{
    s_send_led_raw_enabled = enabled;
    s_send_led_high_z = false;
    s_send_led_raw_level = level;
    if (!enabled) {
        s_send_led_forced = false;
    }
}

void badge_display_set_receive_led_raw(bool enabled, bool level)
{
    s_receive_led_raw_enabled = enabled;
    s_receive_led_high_z = false;
    s_receive_led_raw_level = level;
    if (!enabled) {
        s_receive_led_forced = false;
    }
}

void badge_display_set_send_led_high_z(bool enabled)
{
    s_send_led_high_z = enabled;
    if (enabled) {
        s_send_led_forced = false;
        s_send_led_raw_enabled = false;
    }
}

void badge_display_set_receive_led_high_z(bool enabled)
{
    s_receive_led_high_z = enabled;
    if (enabled) {
        s_receive_led_forced = false;
        s_receive_led_raw_enabled = false;
    }
}

void badge_display_pulse_send(void)
{
    s_send_pulse_ticks = 8;
}

void badge_display_pulse_receive(void)
{
    s_receive_pulse_ticks = 8;
}

void badge_display_play_busy_dance(void)
{
    ESP_LOGI(TAG, "busy dance requested");
    for (uint8_t i = 0; i < BADGE_ID_LED_COUNT; i++) {
        badge_display_set_target_id((uint8_t)(1U << i), false);
        for (uint8_t j = 0; j < 10; j++) {
            vTaskDelay(delay_ticks_at_least_one(10));
        }
    }
}

void badge_display_play_error_dance(void)
{
    ESP_LOGI(TAG, "error dance requested");
    for (uint8_t i = 0; i < 3; i++) {
        badge_display_set_my_id(0x3f, false);
        badge_display_set_target_id(0x3f, false);
        vTaskDelay(pdMS_TO_TICKS(120));
        badge_display_set_my_id(0, false);
        badge_display_set_target_id(0, false);
        vTaskDelay(pdMS_TO_TICKS(120));
    }
}
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

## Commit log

2026-07-02 fix schm
    [badgePCB.kicad_sch]
2026-07-02 qrcode and morsecode
    [badgePCB.kicad_pcb]
2026-07-02 Add README for Small Morse Code Handheld Devices
    Added project description and images for Emefedez variant.
2026-07-02 Added Emefedez Project
    [PCB_Fallout.kicad_pcb, PCB_Fallout.kicad_sch, freerouting.dsn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]
2026-07-02 Fixed formatting
    [PCB_Fallout.kicad_pcb, PCB_Fallout.kicad_sch, freerouting.dsn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]
2026-07-02 BOM + other changes
2026-07-08 esp32-C3 Super Mini Support
2026-07-08 fix led flicker
2026-07-08 fix my id order
    [badge_display.c]
2026-07-08 fix xiao pin order
    [badge_hardware.c]
